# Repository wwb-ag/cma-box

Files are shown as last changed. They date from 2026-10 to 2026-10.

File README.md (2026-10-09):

# The Box

A simple **3d-printable** box for assessing whether the **CMA** participant's equipment satisfies the dimensionality requirements of the desired category.

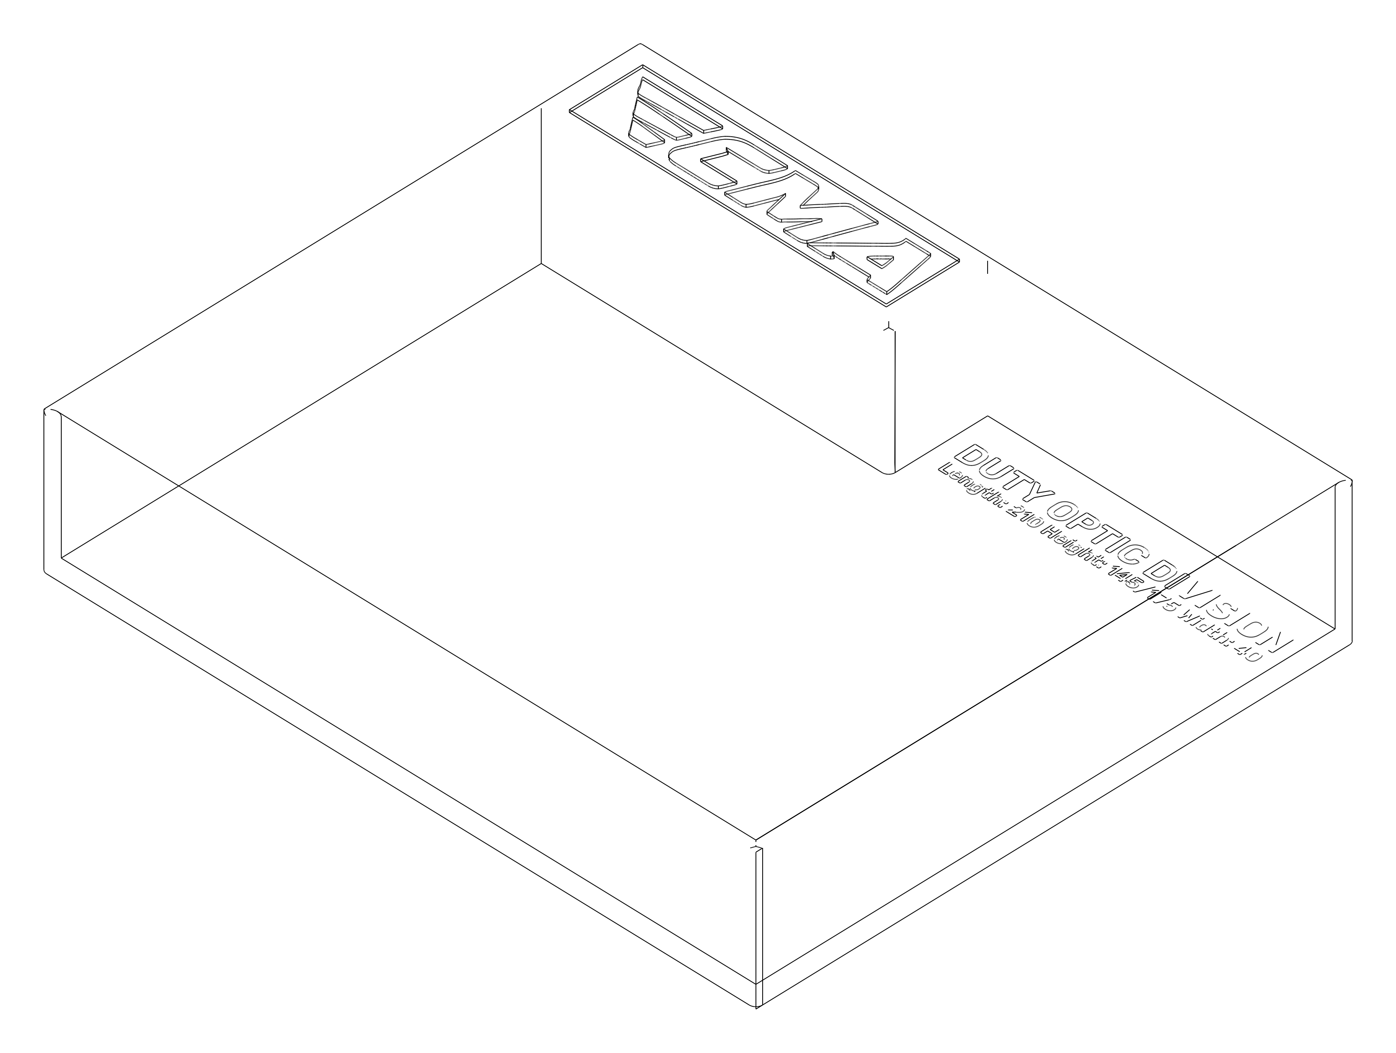
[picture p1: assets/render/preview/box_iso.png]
The box: L-shaped cavity, engraved labels, CMA logo panel


- This repository contains the openscad files, the assets and build scripts.
- You can download the print-ready `.stl` files from the [CMA website](https://example.com).

## Dimensions

Inner dimensions of the box (nominal values, as printed on the labels).
The modeled cavity adds +0.4 mm to every inner dimension (nozzle-width
print clearance), so the printed cavity ends up at least the nominal
size.

### Duty Division (insert installed)

- **Length**: 210 mm
- **Height**: 145 mm
- **Width**: 40 mm

### Duty Optics Division (insert removed)

- **Length**: 210 mm
- **Height**:
  - First half along length: 145 mm
  - Second half along length: 175 mm (optic pocket)
- **Width**: 40 mm

## Design

- Edges, rims, and outer corners are rounded.
- +0.40 mm (one 0.4 mm nozzle width) is added to every nominal inner dimension.
- Wall and floor strength is 3.2mm.
- The final outer dimensions are 216.8 x 181.8 x 43.6 mm

## Printing Notes

- The box and the insert can be printed on a 220x220 bed at the same time (tight fit).
- This is a large part, make sure the bed is level and calibrate before printing.
- We used default settings (15% infill) for all test prints using CR-PLA with a Creality K1C.
- Print takes approximately 8 hours depending on settings and whether the insert is printed alongside the box. One set takes around 230g of PLA (@15% infill), therefore four sets can be printed from a standard 1kg spool.
  - **Box**: 191g of PLA and 6h 45min printing time.
  - **Insert**: 38g of PLA and 1h 15min.
  
## Project Structure and Build Notes

Tested and rendered with `OpenSCAD version 2026.10.03` (any OpenSCAD AppImage
dropped into `bin/` works — `build.sh` picks up `bin/OpenSCAD-*.AppImage`,
git-ignored; binary STL export via `--export-format binstl`) on Ubuntu
2024.04; also verified with `OpenSCAD version 2021.01` (CGAL, same
dimensions - `build.sh` falls back to it when no AppImage is present).

Two design files:

- `openscad/duty_division.scad`: the box
- `openscad/duty_division_insert.scad`: the labeled insert

Three utility scripts:

- `assets/font/create_label_svgs.py`: Regenerate after changing a label string
  (needs Rubik-SemiBold.ttf from the font, not shipped here - see the script's
  error for where it looks):
  `uv run --with fonttools python3 assets/font/create_label_svgs.py`
- `assets/logo/trace_logo.sh`: regenerates the SVG from the AVIF
  (ImageMagick + `uvx vtracer`)
- `assets/render/make_lineart.py`: vector line-art renders for the README
  (black/white outlines from the STLs, hidden-line removed); writes
  PNG + SVG into `assets/render/preview/`:
  `uv run --with numpy --with matplotlib python3 assets/render/make_lineart.py`

One build script:

- `build.sh`

## Acknowledgements

Development of this project was sponsored and carried out by [WWB AG](https://wwb.swiss) for CMA.

## Licenses

- Code build and preprocess scripts: Creative Commons Attribution 4.0 International
- Assets:
  - Logo: CMA proprietary 
  - Font: OFL (`OFL.txt`)

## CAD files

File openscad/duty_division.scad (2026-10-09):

// ============================================================================
// CMA - The Box : Duty Division - CONVERTIBLE (Optics/Non-Optics)
// https://github.com/wwb-ag/cma-box
//
// Combined / convertible gauge box for BOTH divisions:
//   - Duty Division        : gear fits 210 x 145 x 40
//   - Duty Optics Division : gear fits 210 x 175 x 40, but the
//     175 mm height is only needed over HALF the length (the
//     optic sits on one half of the slide).
//
// The cavity is an L: base 210 x 145 x 40 plus a fixed extra
// pocket 105 x 30 x 40 (30 = 175 - 145) in the TOP RIGHT corner
// of the plan view (the matching INSERT sits there). The OUTER
// shape is a regular rectangle
// (216.8 x 181.8 x 43.6): the area left of the pocket is solid
// fill, a flat plaque flush with the rim, carrying the CMA logo
// (inverted relief). The INSERT (duty_division_insert.scad)
// fills the pocket, restoring the plain
// 210 x 145 x 40 version.
//
// LABELS (self-describing gauge):
//   - The insert carries "DUTY DIVISION / Length: 210
//     Height: 145 Width: 40" on its top face -> with the insert
//     in, the reading matches the opening.
//   - The pocket floor (the area covered by the insert) carries
//     "DUTY OPTIC DIVISION / Length: 210 Height: 145/175
//     Width: 40" -> with the insert lifted out, the reading
//     matches the L-shaped opening (145 over one half, 175 over
//     the other).
//   - The plaque (left of the pocket) carries the CMA logo
//     (inverted relief); all text labels are deterministic SVG
//     outlines (see label_svg() below), not text().
//
// CONVEX VERTICAL CORNERS: sharp convex corners deposit extra
// material when printing and bulge slightly. Round them all with
// corner_r (vertical corner radius, full wall height): box = the
// 4 OUTER + the 1 INNER corner where the plaque meets the pocket
// (the L's convex material corner); insert = its 4 outer corners.
// Concave corners stay sharp - only the convex side rounds.
//
// INSERT FIT (both parts):
//   - the insert's plan is 0.4 mm smaller per axis than the
//     pocket (104.8 x 29.6) for drop-in clearance,
//   - its depth is the NOMINAL 40.0, not 40.4: the printed pocket
//     depth comes out ~0.4 short (floor prints a nozzle width
//     thick), so 40.0 sits flush with the rim while 40.4 stood
//     proud.
//
// PRINT CLEARANCE: +0.40 mm (one 0.4 mm nozzle width) is added
// to every nominal inner dimension, because a printed cavity
// comes out up to one nozzle width undersized.
// Print error should therefore be in range +0.00 to +0.80 < 1mm
// The MODELED cavity is 210.4 x 145.4/175.4 x 40.4; the LABELS 
// still state the nominal 210 / 145 / 175 / 40.
//
// Rounded edges: TRUE round fillets on
// both top rim edges - outer rim radius 1.0 mm, inner rim radius
// 2.0 mm (double the outer), applied to every opening edge
// (incl. the pocket and shelf edges) and around the outer top
// perimeter.
//
// Inner dimensions (per README, nominal; + fit = modeled):
//   Length : 210 mm   Height : 145 mm (+30 over half length)
//   Width  :  40 mm
//
// Wall strength: 3.2 mm (= 8 perimeter lines at 0.4 mm nozzle).
//
// ORIENTATION NOTE - spec dims are the firearm's natural
// orientation (length x height seen from the side, width =
// thickness). The box lies flat on the bench: LENGTH x HEIGHT
// is the footprint, WIDTH (40 mm) is vertical. Built in print
// orientation: X = Length, Y = Height, Z = Width (walls up from
// a 3.2 mm floor). Footprint 216.8 x 181.8 mm fits the 220 x
// 220 bed (K1C).
// ============================================================================

/* [Parameters] */
// Wall thickness [mm] (multiple of 0.4 nozzle line width)
wall = 3.2; // [1:0.1:10]
// Printer clearance [mm]: one 0.4 mm nozzle width added to every
// NOMINAL inner dimension (printed cavities run up to a nozzle
// width undersized). Labels always print the nominal values.
fit = 0.4; // [0:0.05:1]
// Nominal inner length [mm] (firearm length)
inner_l = 210; // [10:1:400]
// Nominal inner height, non-optic half [mm]
inner_h = 145; // [10:1:400]
// Nominal inner width [mm] (firearm thickness = vertical wall height)
inner_w = 40; // [10:1:200]
// Extra height of the optic half [mm] (175 = inner_h + opt_h);
// NOT clearanced - it is a delta, the fit rides on inner_h
opt_h = 30; // [0:1:60]
// Fillet radius on the OUTER top rim edge [mm] (0 = sharp)
outer_r = 1.0; // [0:0.1:2]
// Fillet radius on the INNER top rim edge [mm]
// (double the outer; clamped so outer + inner <= wall)
inner_r = 2.0; // [0:0.1:3]
// Vertical corner radius [mm] (0 = sharp). Rounds the CONVEX
// vertical edges (4 outer + the L's inner corner): sharp convex
// corners deposit extra material in FDM and bulge slightly
corner_r = 2.0; // [0:0.5:4]
// CMA logo on the plaque (top-left): INVERTED relief - recessed
// design panel with the bars/letters raised (elements keep their
// current size; logo_w = element width in mm, 0 = no logo)
logo_w = 90; // [0:1:110]
// Logo recess depth [mm]
logo_depth = 0.8; // [0.4:0.1:2]
// Engraved label on the POCKET FLOOR (visible when the insert is
// removed) - on/off only. The wording lives in
// assets/font/label_svgs/floor_*.svg (generated by
// assets/font/create_label_svgs.py), not in this file.
floor_label = true; // [true,false]
// Floor label sizes [mm] - the pocket band is only 30 mm deep
// (105.2 mm long), keep the lines small enough to fit it.
floor_label_size = 3.6; // [3:0.5:20]
floor_title_size = 6.5; // [3:0.5:20]  (title line)
// Label engrave depth [mm]
label_depth = 0.8; // [0.4:0.1:2]
// Line spacing: center-to-center distance = label_lh x dims-line size
label_lh = 2.0; // [1:0.1:3]
// Label rotation [deg] (0 = reads with +y up)
label_rot = 0; // [0:15:359]

// Derived (nominal + fit = modeled/printed geometry)
il = inner_l + fit; // 210.4 mm (X)
ih = inner_h + fit; // 145.4 mm (Y, non-optic half)
iw = inner_w + fit; //  40.4 mm (Z)
pocket_l = il / 2; // 105.2 mm (half length)
inner_ht = ih + opt_h; // 175.4 mm (Y, optic half)
outer_l = il + 2 * wall; // 216.8 mm (X)
outer_hb = ih + 2 * wall; // 151.8 mm (Y, non-optic half)
outer_ht = inner_ht + 2 * wall; // 181.8 mm (Y, total)
outer_w = iw + wall; //  43.6 mm (Z)
o_c = min(outer_r, wall / 2);
i_c = max(0, min(inner_r, wall - o_c));

// ---- Outer shell (regular rectangle, floor at Z = 0) -----------------------
// Full 216.8 x 181.8 x 43.6 block. The area LEFT of the optic
// pocket (x < 0, y > 72.7) is solid fill - a flat plaque flush
// with the rim, carrying the CMA logo. Uses a bit more
// material; the print footprint is unchanged.
module outer_shell() {
  translate([-outer_l / 2, -outer_hb / 2, 0])
    cube([outer_l, outer_ht, outer_w]);
}

// ---- Outer rim fillet cutter (top perimeter, radius r) ---------------------
// Rounds the four horizontal edges where the outer wall faces
// meet the top face. Per edge: R = intersection(the two outer
// half-slabs) MINUS the fillet cylinder (axis along the edge,
// radius r, centered at (face - r, top - r)); subtract R.
module outer_fillet_cutter(r) {
  L = 400;
  nf = 64;
  // arc center z
  ez = outer_w - r;
  // arc center x (right/left)
  ex = outer_l / 2 - r;
  // arc center y (top edge)
  ey = -outer_hb / 2 + outer_ht - r;
  // arc center y (bottom edge)
  eyb = -outer_hb / 2 + r;
  // +x and -x top edges
  for (s = [1, -1]) {
    difference() {
      intersection() {
        translate([s == 1 ? ex : -outer_l / 2, -L, ez])
          cube([s == 1 ? L : r, 2 * L, r + 1]);
        translate([-L, -L, ez])
          cube([2 * L, 2 * L, r + 1]);
      }
      translate([s * ex, 0, ez])
        rotate([90, 0, 0])
          cylinder(r=r, h=2 * L, center=true, $fn=nf);
    }
  }
  // +y and -y top edges (the inward slab width is r, outward is r+1)
  for (s = [1, -1]) {
    difference() {
      intersection() {
        translate([-L, s == 1 ? ey : eyb - r, ez])
          cube([2 * L, s == 1 ? r + 1 : r, r + 1]);
        translate([-L, -L, ez])
          cube([2 * L, 2 * L, r + 1]);
      }
      translate([0, s == 1 ? ey : eyb, ez])
        rotate([0, 90, 0])
          cylinder(r=r, h=2 * L, center=true, $fn=nf);
    }
  }
}

// ---- Cavity (L-prism, open top) --------------------------------------------
// Pocket in the TOP RIGHT: x in [0, 105.2], y in [72.7, 102.7].
module cavity() {
  union() {
    // base 210.4 x 145.4
    translate([-il / 2, -ih / 2, wall])
      cube([il, ih, iw]);
    // optic pocket 105.2 x 30, top-right
    translate([0, ih / 2, wall])
      cube([pocket_l, opt_h, iw]);
  }
}
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

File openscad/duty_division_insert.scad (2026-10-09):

// ============================================================
// CMA - The Box : CONVERTIBLE INSERT (filler block)
// https://github.com/wwb-ag/cma-box
//
// Fills the optic pocket of duty_division.scad, restoring the
// plain 210 x 145 x 40 gauge opening. Keep it inserted to test
// the Duty (non-optic) Division, remove it to test the Duty
// Optics Division.
//
// LABELS (self-describing gauge): the top face carries
//   "DUTY DIVISION / Length: 210 Height: 145 Width: 40"
// matching the opening when the insert is in place. The pocket
// floor underneath (see duty_division.scad) carries "DUTY OPTIC
// DIVISION / Length: 210 Height: 145/175 Width: 40" for the
// insert-removed case. The insert is a plain drop-in (no keyway).
//
// Dimensions (match duty_division.scad):
//   Length 104.8 mm x Height 29.6 mm x Depth 40.0 mm
//   = ((210 + 0.4) / 2 - 0.4)  x  (30 - 0.4)  x  40
//   - plan (length/height): 0.4 mm smaller per axis than the
//     pocket for drop-in clearance,
//   - depth: NOMINAL 40.0, NOT 40.4 - the printed pocket depth
//     comes out ~0.4 short (floor prints a nozzle width thick),
//     so 40.0 sits level with the box rim while 40.4 stood proud.
//   If you change the box's inner_l / inner_w / fit, change
//   these to match.
//
// CONVEX VERTICAL CORNERS: all 4
// outer corners are rounded with corner_r (vertical corner
// radius, full height) - sharp convex corners deposit extra
// material when printing and bulge slightly. Label stays clear
// of the rounds.
//
// Printed in use position: 104.8 x 29.6 mm footprint on the bed,
// 40.0 mm tall, engraved label side UP (no supports in that
// orientation), fits the K1C bed easily.
// ============================================================

/* [Parameters] */
// Pocket length [mm] = (inner_l + fit) / 2 - 0.4 of the box
// (105.2 - 0.4 drop-in clearance)
body_l = 104.8;   // [10:0.1:400]
// Pocket height [mm] = opt_h - 0.4 of the box (30 - 0.4)
body_h = 29.6;    // [1:0.1:60]
// Pocket depth [mm] = NOMINAL inner_w of the box (40, not 40.4:
// printed pocket depth is ~0.4 short, so 40.0 sits flush)
body_d = 40.0;    // [10:0.1:200]
// Vertical corner radius [mm] (0 = sharp): rounds the 4 convex
// outer corners (sharp convex corners bulge when printing)
corner_r = 2.0;   // [0:0.5:4]
// Top-edge fillet radius [mm] (0 = sharp): rounds the 4 edges
// around the top face (same treatment as the box rim fillets)
top_fillet_r = 1.0; // [0:0.1:2]
// Label text height [mm] - top face is only 105 x 30 mm, keep
// the dimension line small enough to fit the 105 mm length
label_size = 4.0; // [3:0.5:20]
label_title_size = 8.0; // [4:0.5:20]  (title line)
// Label engrave depth [mm]
label_depth = 0.8;  // [0.4:0.1:2]
// Line spacing: center-to-center distance = label_lh x dims-line size
label_lh = 2.0;     // [1:0.1:3]
// Label rotation [deg] (0 = reads with +y up, as modeled)
label_rot = 0;      // [0:15:359]

// ---- Brand-font label line as SVG ----------------------------
// The Rubik label lines live in assets/font/label_svgs/ (generated
// by assets/font/create_label_svgs.py). Every SVG is normalized to
// CAP HEIGHT = 100 units; OpenSCAD's viewBox import maps 1 unit ->
// 0.352778 mm, so the cap imports as 35.2778 mm and scaling by
// size/35.2778 sets the cap height to 'size' mm. adv_u/h_u = the
// SVG's advance width and height in units (see the comment baked
// into each SVG). The import includes the y-flip (reads correctly
// from above) - do NOT mirror it.
module label_svg(file, adv_u, h_u, size) {
    f = size / 35.2778;
    translate([-adv_u * 0.352778 * f / 2, -h_u * 0.352778 * f / 2, 0])
        scale([f, f, 1])
        linear_extrude(label_depth + 0.1)
        import(file, center = false);
}

// ---- Label on the insert top face --------------------------
// States the NOMINAL gauge dims of the box with the insert in:
// 210 x 145 x 40 (Duty Division). Two lines (title + dims), line
// centers spaced label_lh x size apart; title on top = +y side.
module label_module() {
    lh = label_size * label_lh;
    // title line (larger, reads first)
    translate([body_l / 2, body_h / 2 + lh / 2, body_d - label_depth])
        rotate([0, 0, label_rot])
        label_svg("../assets/font/label_svgs/insert_title.svg",
                  1047.29, 102.86, label_title_size);
    // dimensions line
    translate([body_l / 2, body_h / 2 - lh / 2, body_d - label_depth])
        rotate([0, 0, label_rot])
        label_svg("../assets/font/label_svgs/insert_dims.svg",
                  2354.29, 135.86, label_size);
}

// ---- Convex vertical corner rounding ------------------------
// TRUE tangent round on each of the 4 convex outer corners:
// cutter = corner block (r x r on the material side, full
// height) MINUS a cylinder of radius r centered INSIDE the
// material at (r, r) from the corner - leaves a smooth quarter
// cylinder tangent to both faces (not the cuspy "quarter
// circle" of a cylinder centered on the corner vertex).
module corner_round_cutter(r) {
    nf = 64;
    for (c = [[0, 0, 1, 1], [body_l, 0, -1, 1],
              [0, body_h, 1, -1], [body_l, body_h, -1, -1]]) {
        x0 = c[2] < 0 ? c[0] - r : c[0];
        y0 = c[3] < 0 ? c[1] - r : c[1];
        difference() {
            translate([x0, y0, -1])
                cube([r, r, body_d + 2]);
            translate([c[0] + c[2] * r, c[1] + c[3] * r, -1])
                cylinder(r = r, h = body_d + 2, $fn = nf);
        }
    }
}

// ---- Top-edge fillet (around the top face, radius r) --------
// Rounds the 4 horizontal edges of the top face. Per edge: band
// slab on the material side (r wide, from top-r to top) MINUS the
// fillet cylinder (axis along the edge, center at (face -/+ r,
// top - r)) - same pattern as the box rim fillets, tangent to
// the face and to the top plane.
module top_fillet_cutter(r) {
    nf = 64;
    L = 400;
    ez = body_d - r;
    // edges along X: y = 0 (material +y) and y = body_h (material -y)
    for (e = [[0, 1], [body_h, -1]]) {
        y_e = e[0]; s = e[1];
        ylo = s == 1 ? y_e : y_e - r;
        difference() {
            translate([-L, ylo, ez])
                cube([2 * L, r, r]);
            translate([0, y_e + s * r, ez])
                rotate([0, 90, 0])
                    cylinder(r = r, h = 2 * L, center = true, $fn = nf);
        }
    }
    // edges along Y: x = 0 (material +x) and x = body_l (material -x)
    for (e = [[0, 1], [body_l, -1]]) {
        x_e = e[0]; s = e[1];
        xlo = s == 1 ? x_e : x_e - r;
        difference() {
            translate([xlo, -L, ez])
                cube([r, 2 * L, r]);
            translate([x_e + s * r, 0, ez])
                rotate([90, 0, 0])
                    cylinder(r = r, h = 2 * L, center = true, $fn = nf);
        }
    }
}

// ---- Solid -------------------------------------------------
difference() {
    // body: pocket fill minus 0.4 per plan axis
    translate([0, 0, 0])
        cube([body_l, body_h, body_d]);
    if (corner_r > 0)
        corner_round_cutter(corner_r);
    if (top_fillet_r > 0)
        top_fillet_cutter(top_fillet_r);
    label_module();
}

echo(str("Insert body: ", body_l, " x ", body_h, " x ", body_d, " mm (print height ", body_d, " mm, footprint ", body_l, " x ", body_h, " mm)"));
echo(str("Corner rounds: r ", corner_r, " mm on the 4 outer corners; top-edge fillet r ", top_fillet_r, " mm"));
echo(str("Label: \"DUTY DIVISION / Length: 210 Height: 145 Width: 40\" ", label_size, " mm, depth ", label_depth, " mm"));

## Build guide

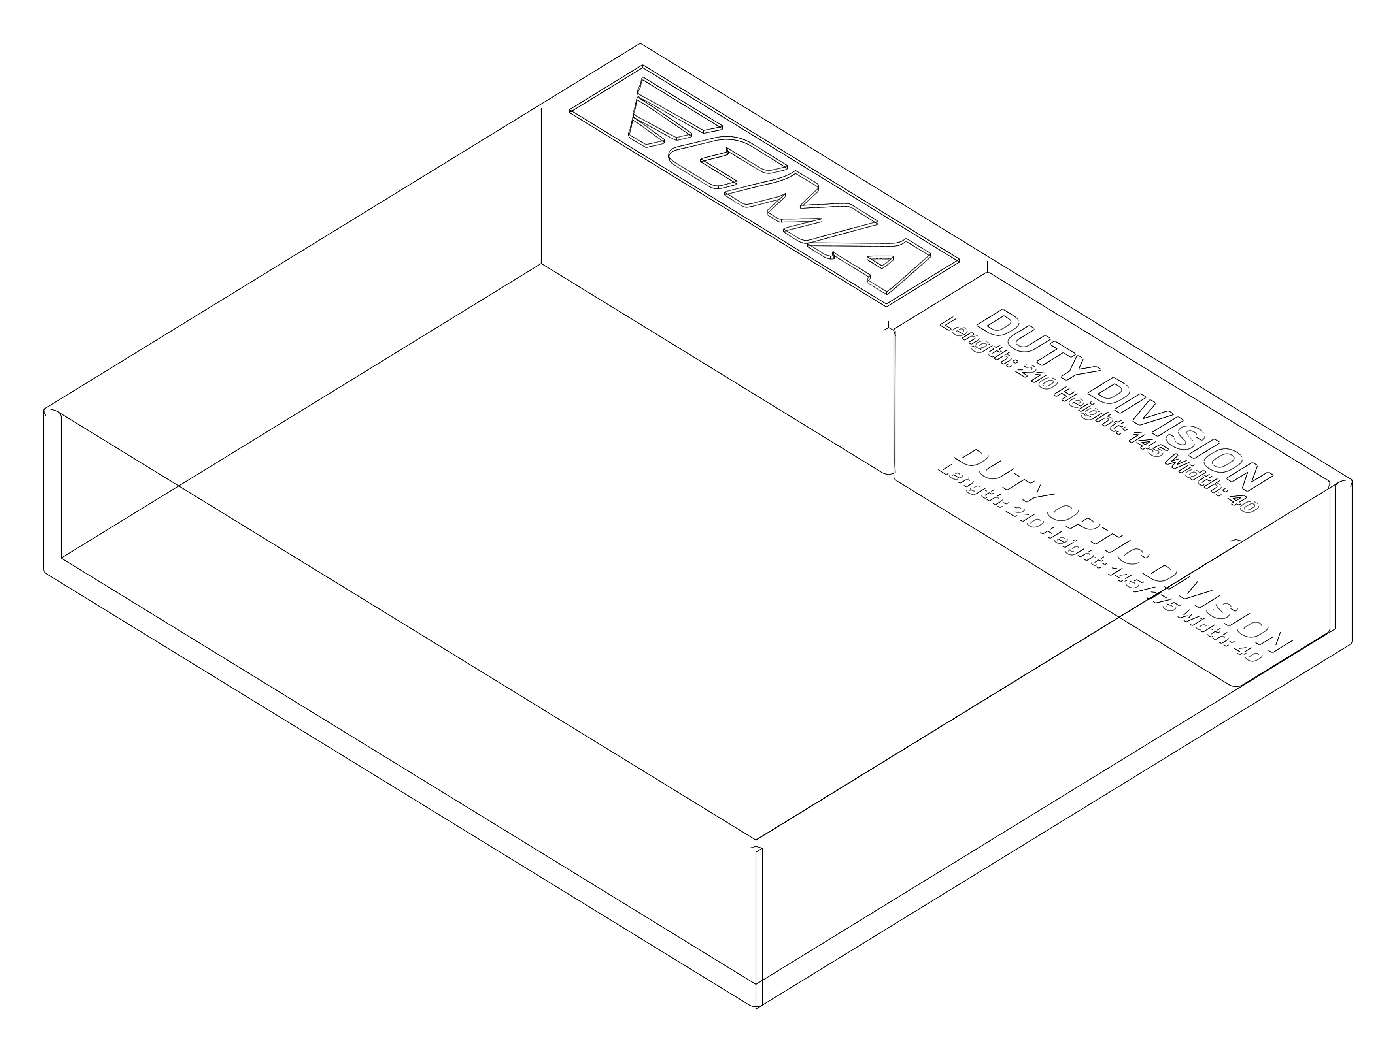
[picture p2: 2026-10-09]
assets/render/preview/set_assembled.png
